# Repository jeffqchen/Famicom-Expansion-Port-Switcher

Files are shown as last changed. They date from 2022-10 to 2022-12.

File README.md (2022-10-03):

# Famicom Expansion Port Switcher Mod

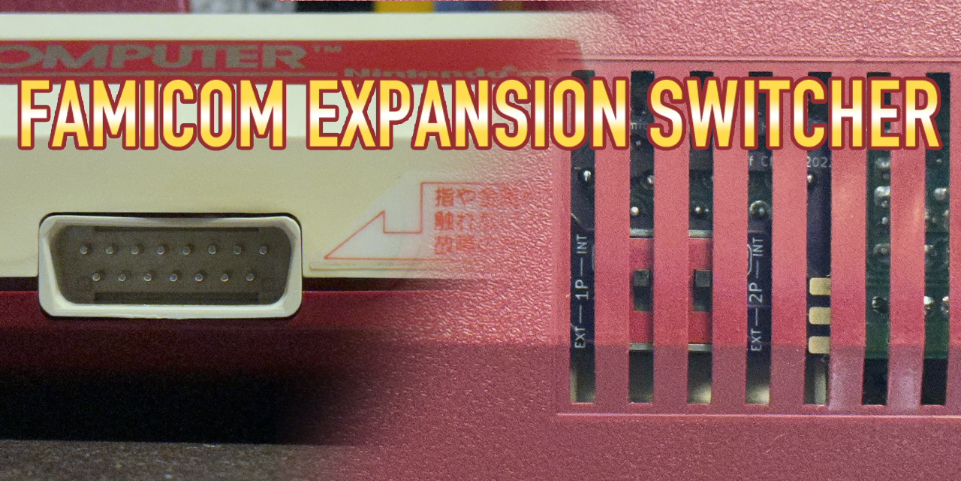
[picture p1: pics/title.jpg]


The expansion ports on the Japanese Famicom consoles have a problem - some western games are incompatible with the controllers connected to this port, due to the fact that this expansion port did not exist on the NES, and therefore was ignored by some devs.

Significant Titles Affected:
- Arkanoid II
- Battletoads
- Dragon's Lair
- Paperboy
- Pinball
- RoboCop 2/3
- Star Force
- Super Mario Bros. USA
- Snake Rattle'n'Roll
- Terminator 1/2
- Tetris (Tengen)
- Zelda II - The Adventure of Link

I created the [FamiCoun](https://github.com/jeffqchen/FamiCoun-Famicom-Front-Expansion-NES-SNES-Adapter) and the [TwinDiamond](https://github.com/jeffqchen/TwinDiamond-Twin-Famicom-Expansion-to-NES-SNES-Controller-Adapter) a few years ago and both suffered from this programming oversight by these devs. So it is only natural for me to take matters into my own hands to fix it.

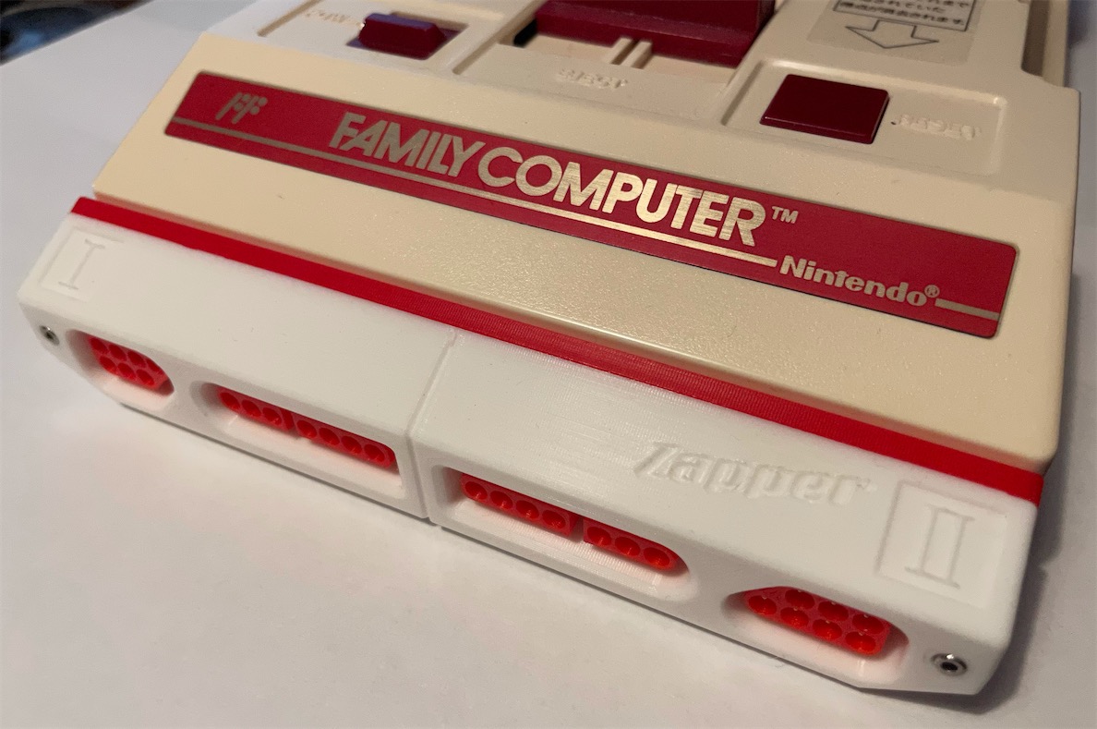
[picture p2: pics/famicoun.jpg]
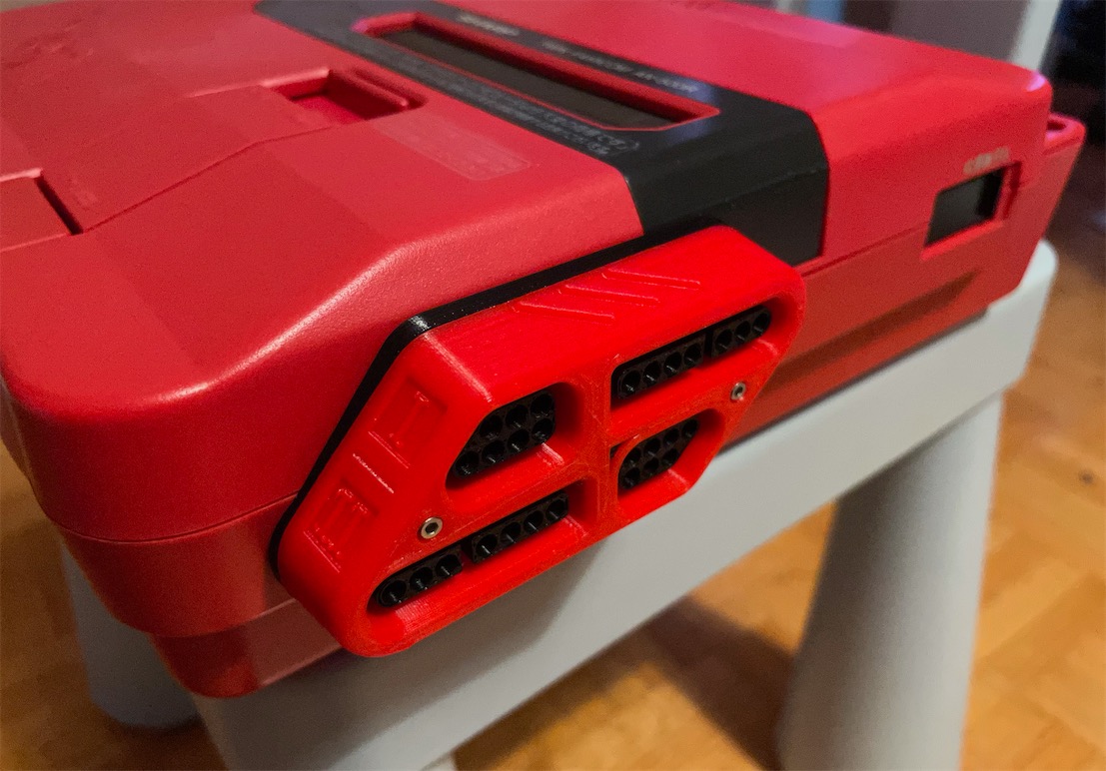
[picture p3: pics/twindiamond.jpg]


This switcher mod will enable you to switch the role of the expansion controllers between internal and external. It requires experience in console modding and might not be friendly for everybody. Please keep this in your mind before attempting.

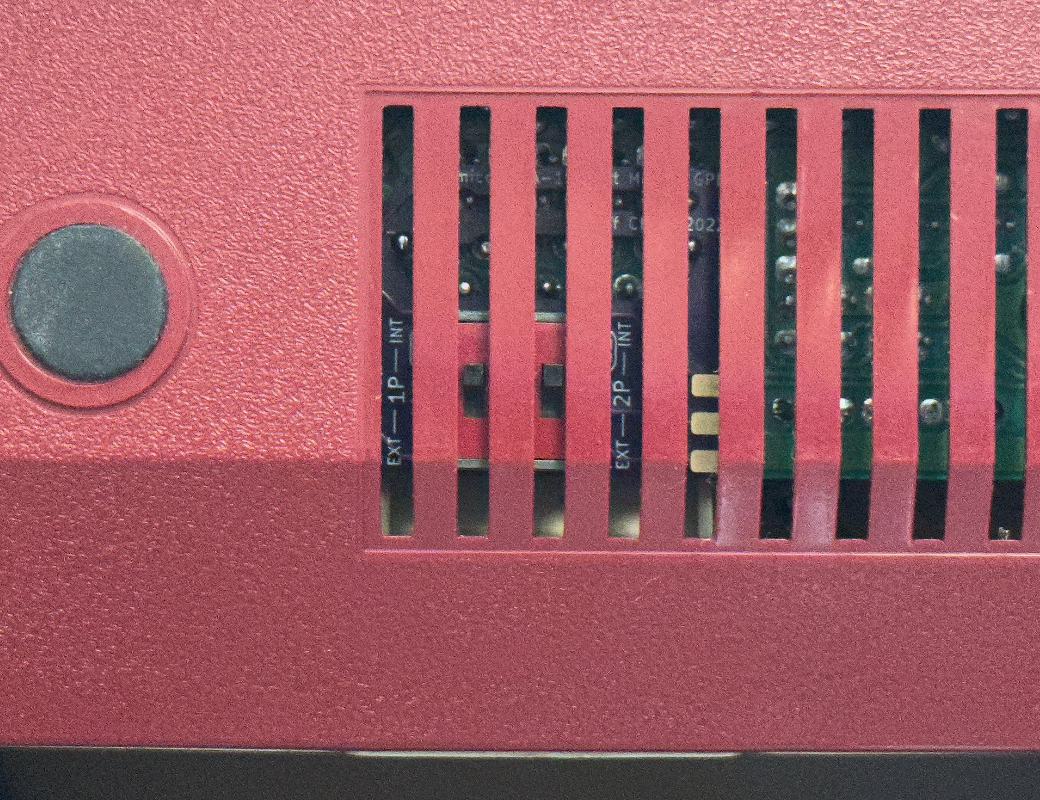
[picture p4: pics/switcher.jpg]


Details are provided in the [Project Wiki](https://github.com/jeffqchen/Famicom-Expansion-Port-Switcher/wiki), separated by console models and motherboard revisions.

-----
## Special Thanks
Voultar (for insisting on a proper logic circuit implementation)
- [Twitter](https://twitter.com/Voultar)

Redherring32 (for providing the board scan of Famicom GPM for reference)
- [Twitter](https://twitter.com/redherring32)
-----

Shield: [][cc-by-sa]

This work is licensed under a
[Creative Commons Attribution-ShareAlike 4.0 International License][cc-by-sa].

[][cc-by-sa]

[cc-by-sa]: http://creativecommons.org/licenses/by-sa/4.0/
[cc-by-sa-image]: https://licensebuttons.net/l/by-sa/4.0/88x31.png
[cc-by-sa-shield]: https://img.shields.io/badge/License-CC%20BY--SA%204.0-lightgrey.svg

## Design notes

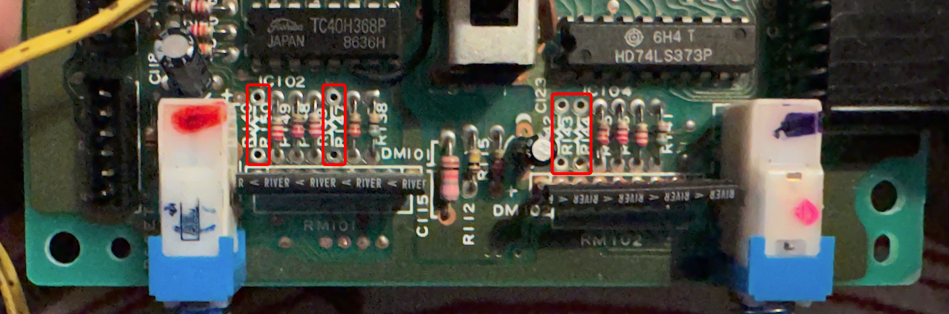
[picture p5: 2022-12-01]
pics/Twins/prepare_motherboard.jpg

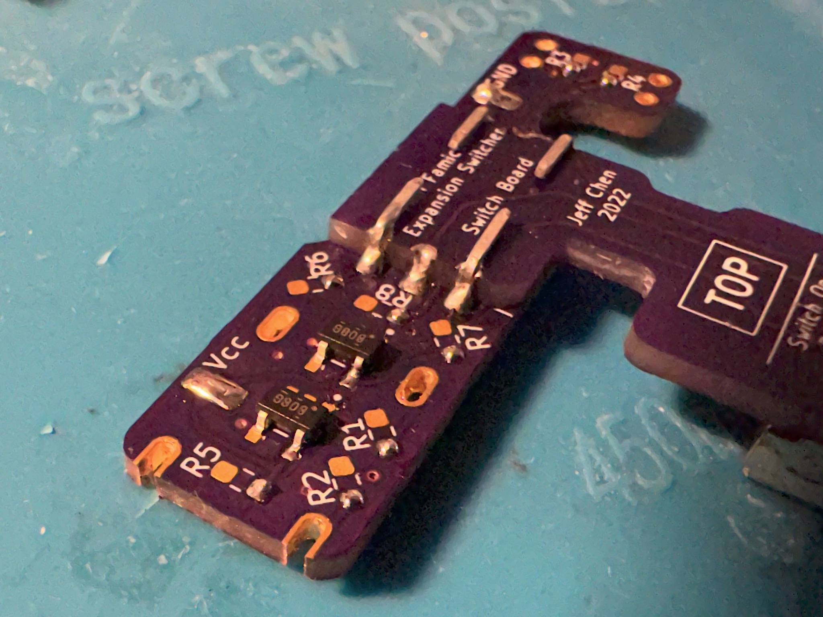
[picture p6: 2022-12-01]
pics/Twins/populate_01.jpg

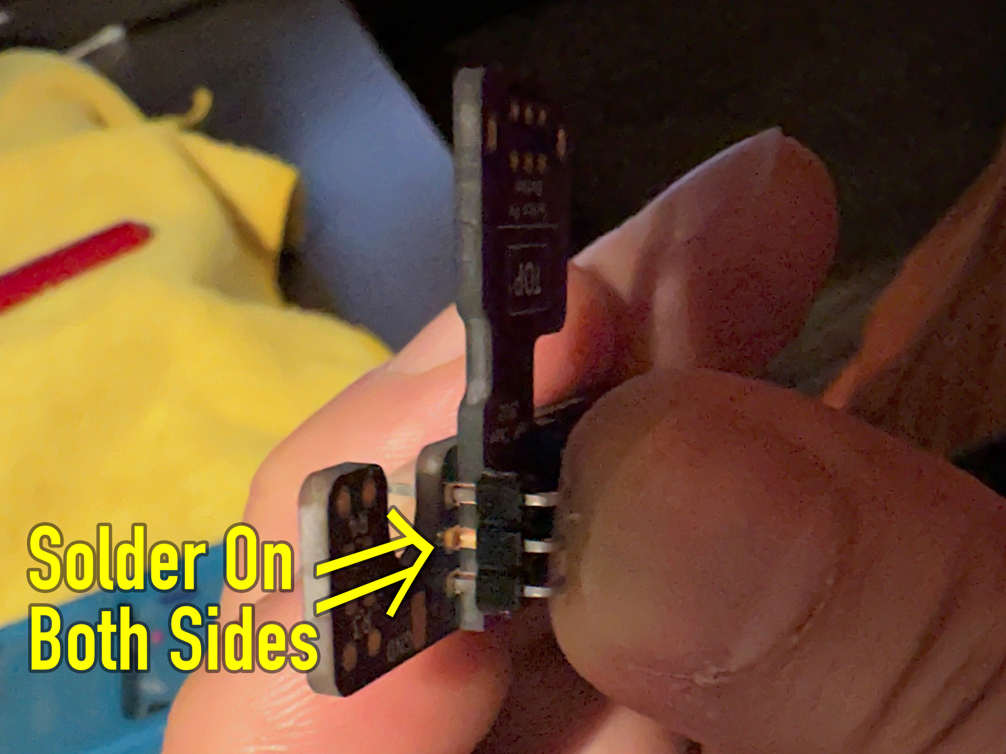
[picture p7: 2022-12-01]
pics/Twins/optional_pin_02.jpg

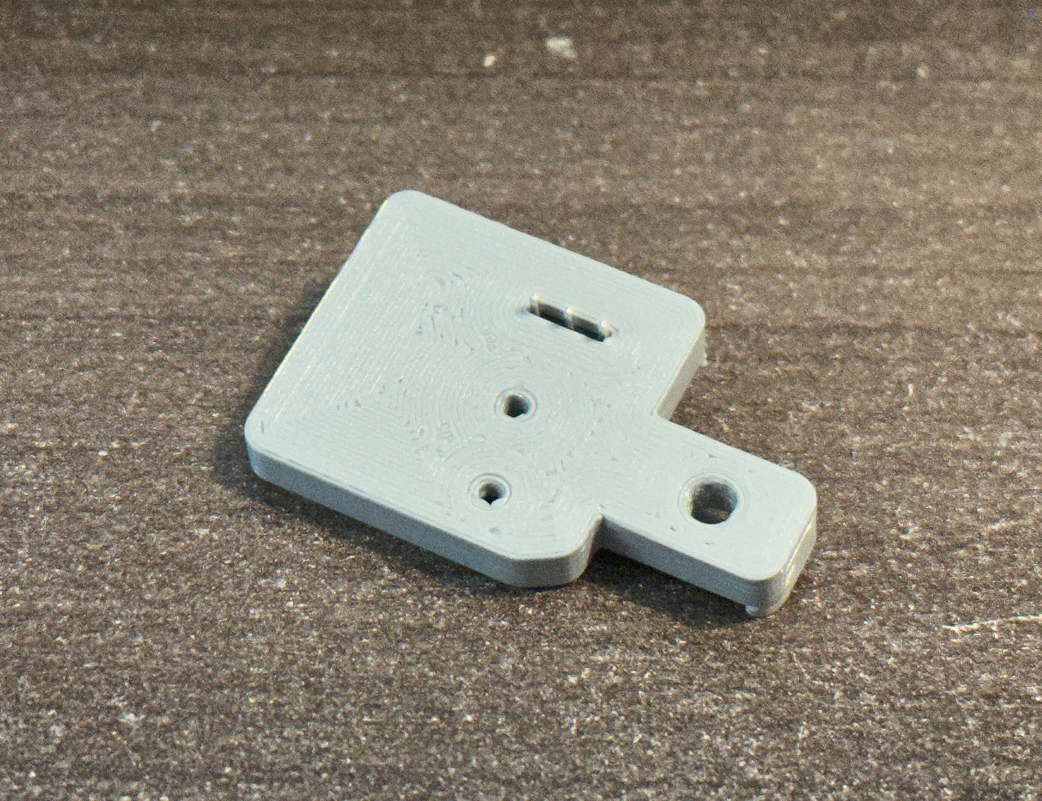
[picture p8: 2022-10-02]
pics/Famicom/GPM/trim_02.jpg

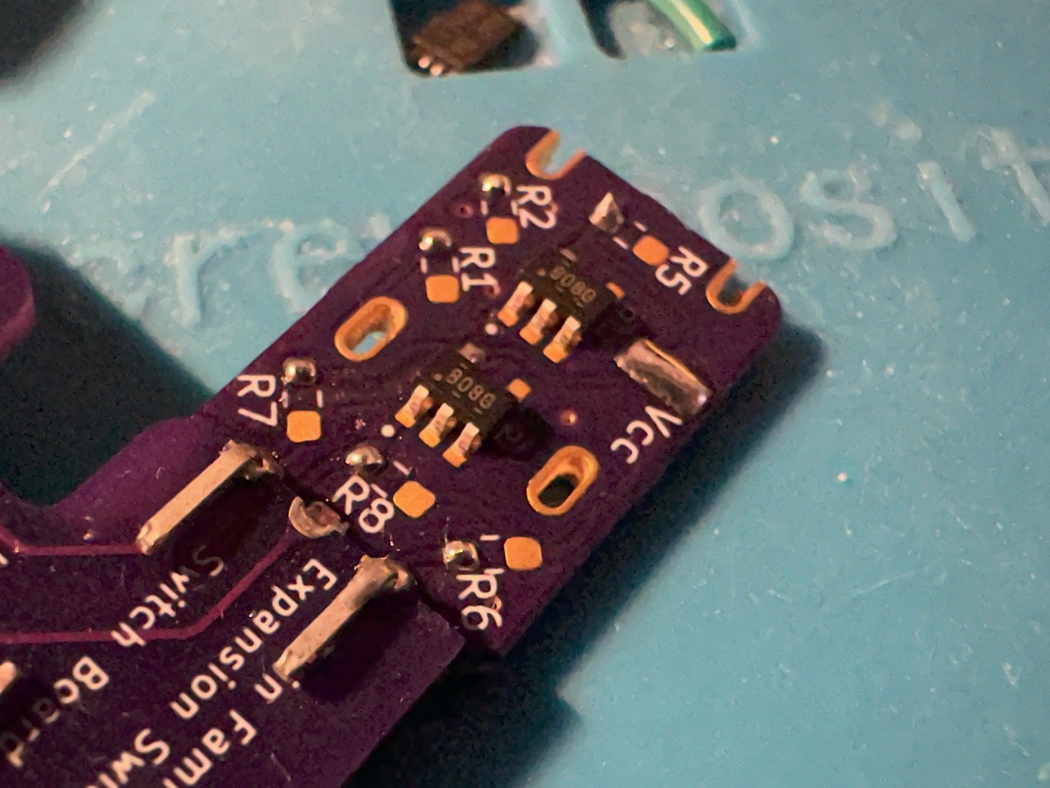
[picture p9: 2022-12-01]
pics/Twins/populate_02.jpg

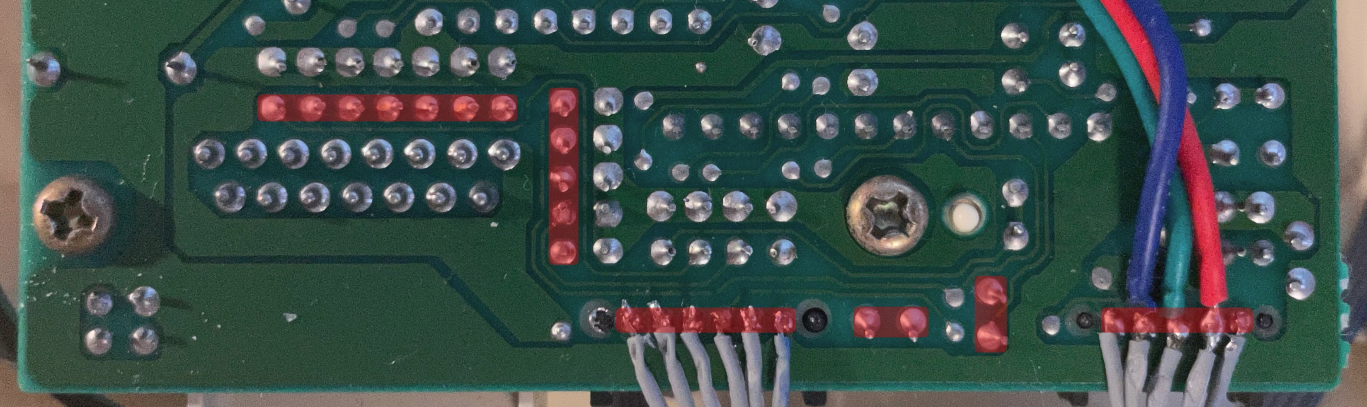
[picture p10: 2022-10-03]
pics/Famicom/GPM/straightenpins_01.jpg

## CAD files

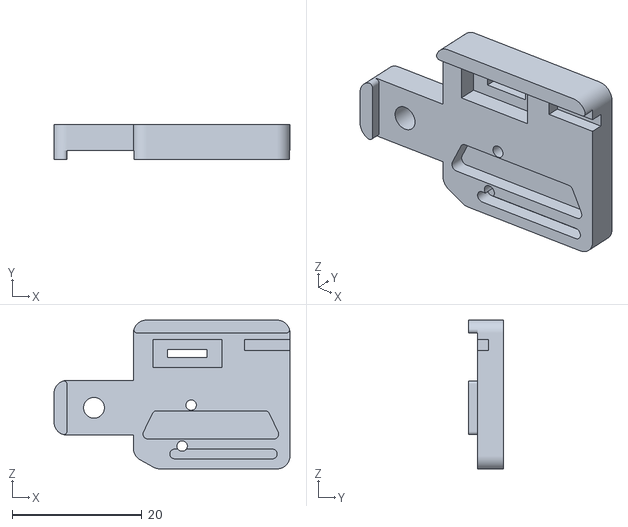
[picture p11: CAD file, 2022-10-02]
3D Print/Famicom/GPM/Drilling Jig.stl
36.3 x 5.40 x 22.9

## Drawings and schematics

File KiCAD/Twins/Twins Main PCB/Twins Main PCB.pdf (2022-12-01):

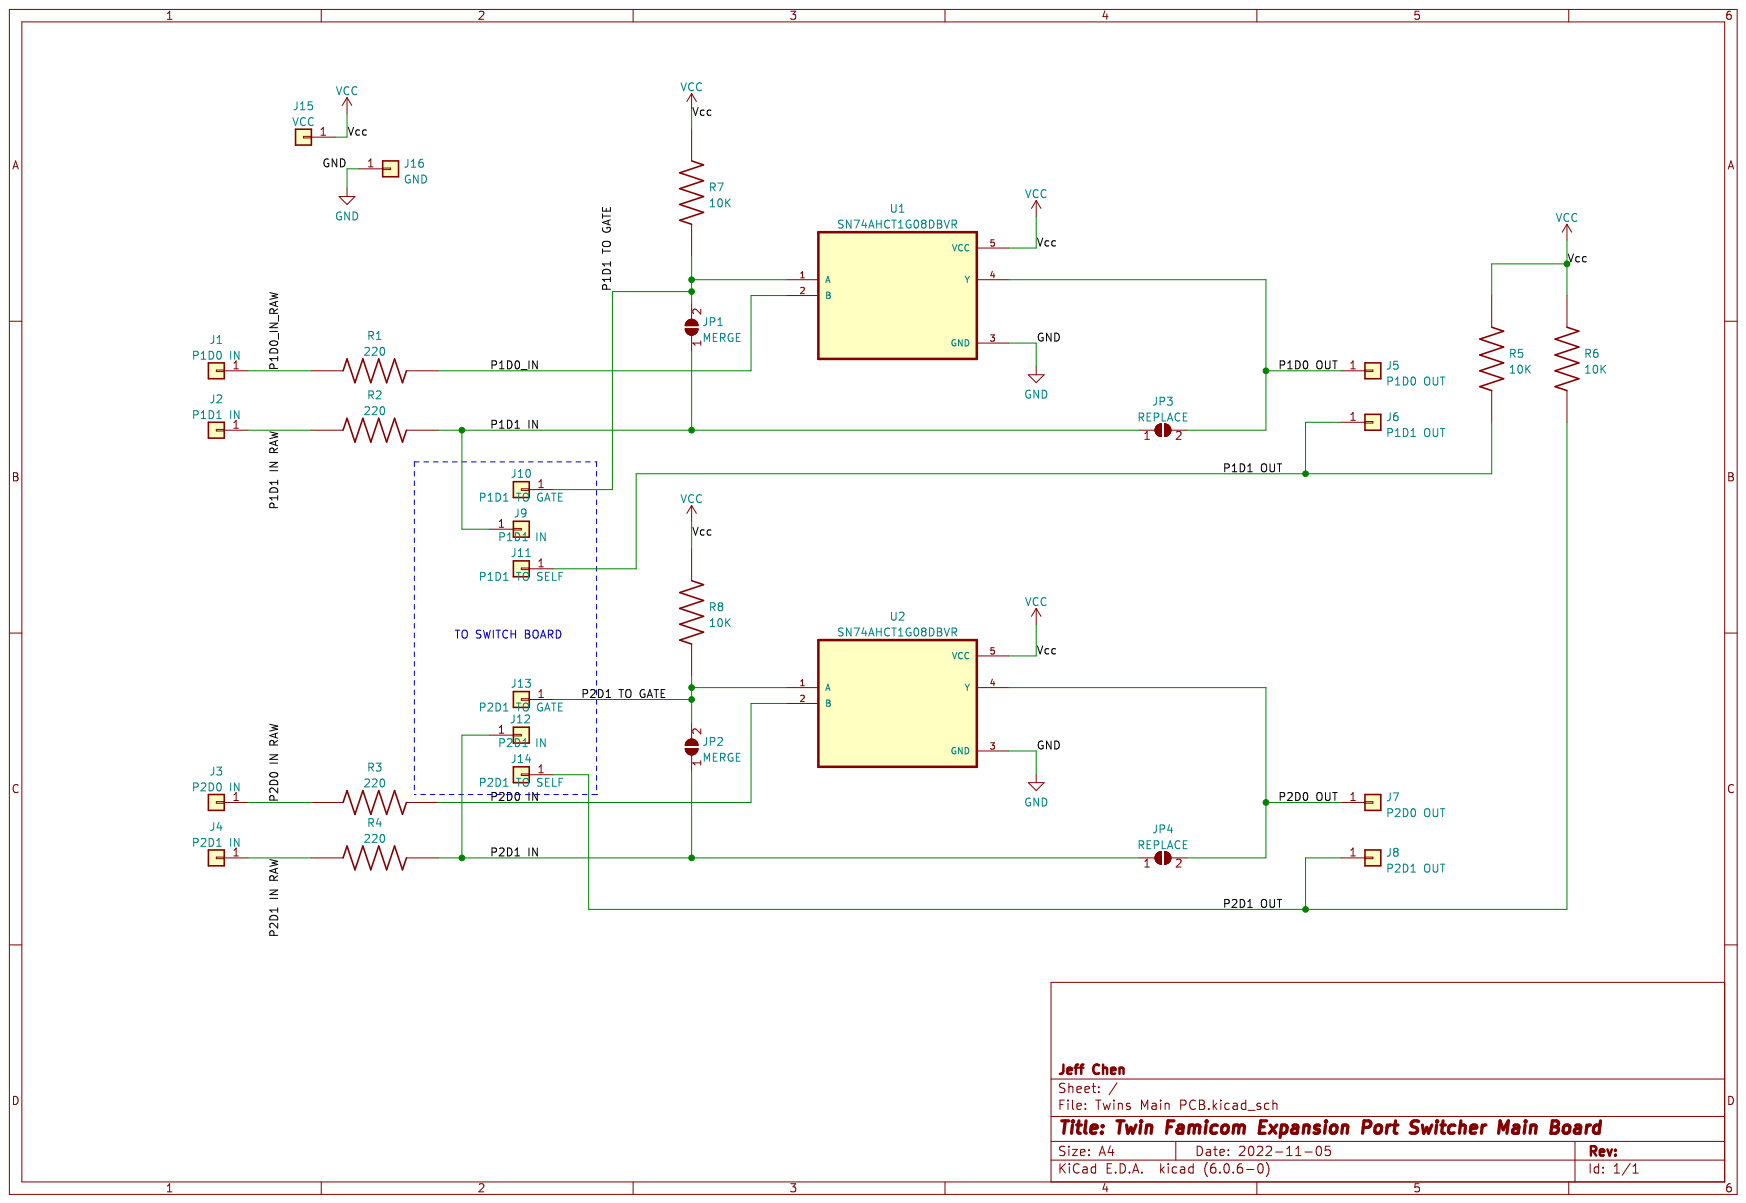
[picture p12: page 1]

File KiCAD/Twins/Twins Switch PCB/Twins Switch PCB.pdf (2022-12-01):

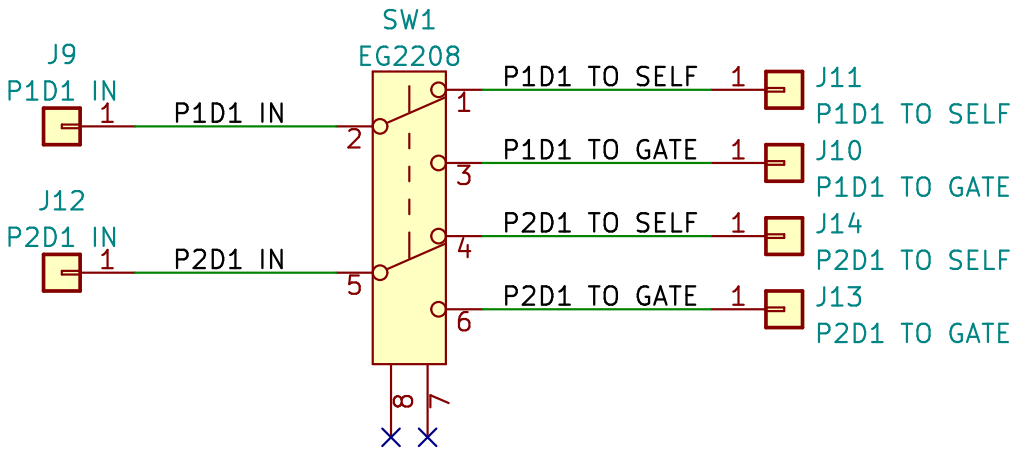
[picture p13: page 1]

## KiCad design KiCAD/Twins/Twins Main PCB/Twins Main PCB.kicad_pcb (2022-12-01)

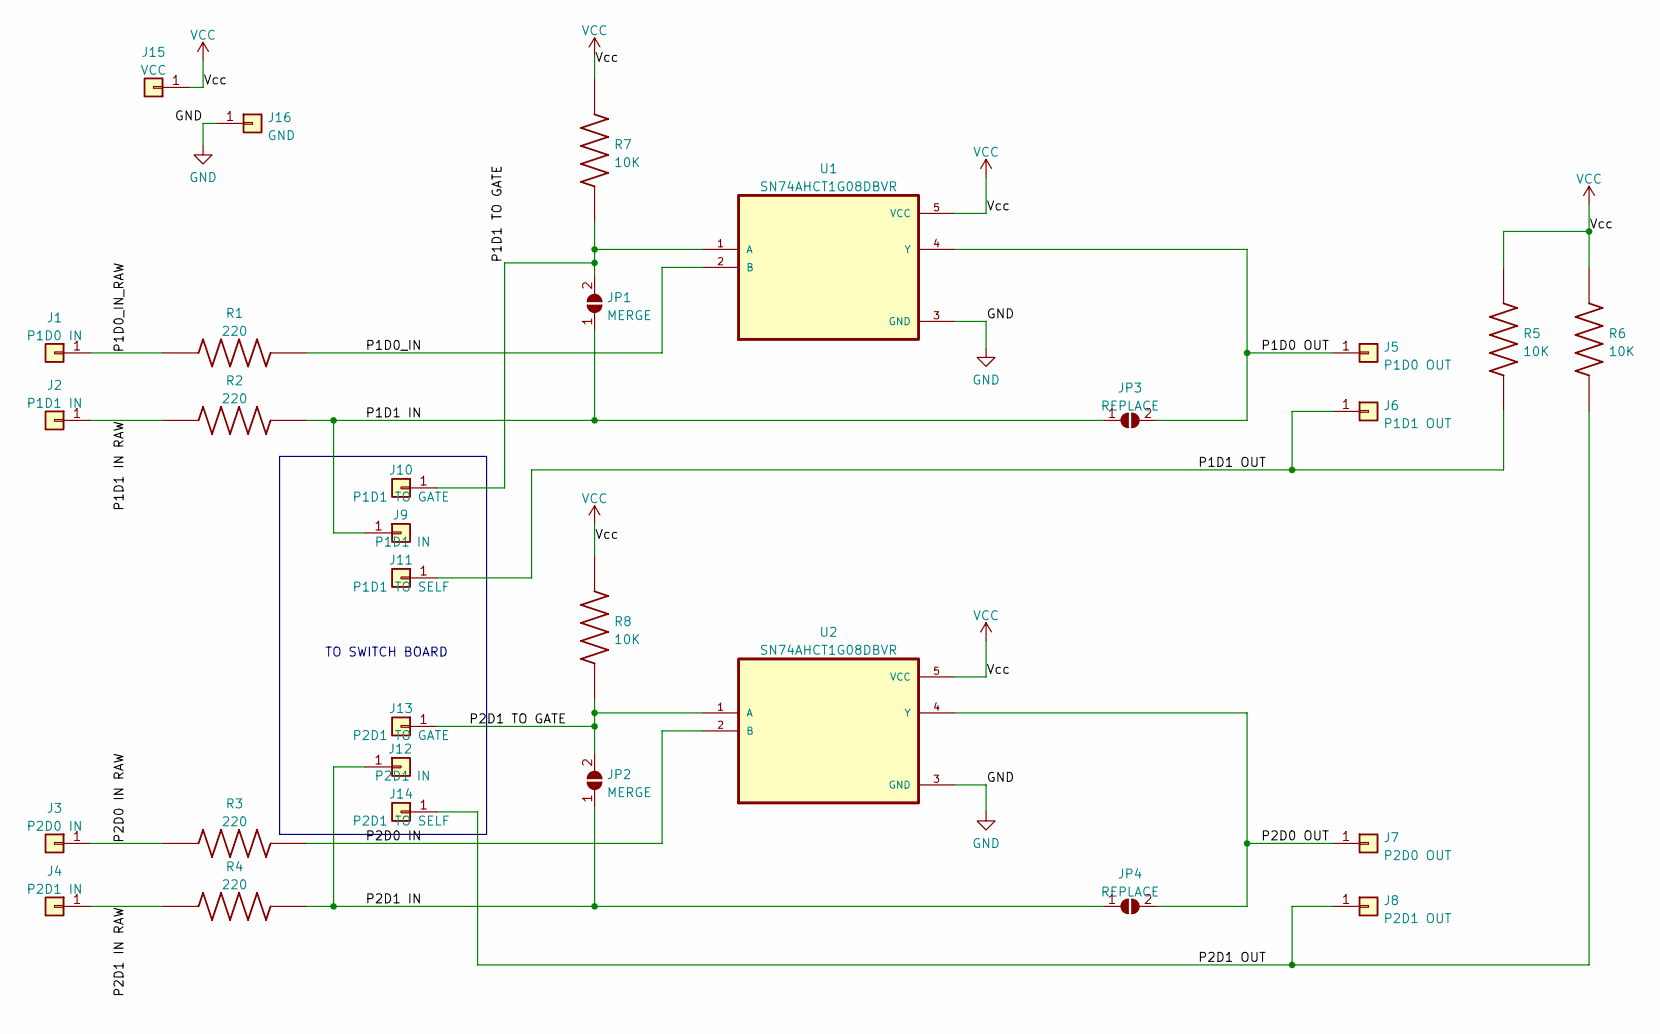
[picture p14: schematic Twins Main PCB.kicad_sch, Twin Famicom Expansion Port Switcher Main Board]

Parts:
J1: P1D0 IN; Long Via
J2: P1D1 IN; Long Via
J3: P2D0 IN; Short Via
J4: P2D1 IN; Short Via
J5: P1D0 OUT; Long Via
J6: P1D1 OUT; Long Via
J7: P2D0 OUT; Short Via
J8: P2D1 OUT; Short Via
J9: P1D1 IN; Landing Pad
J10: P1D1 TO GATE; Landing Pad
J11: P1D1 TO SELF; Landing Pad
J12: P2D1 IN; Landing Pad
J13: P2D1 TO GATE; Landing Pad
J14: P2D1 TO SELF; Landing Pad
J15: VCC; Single Pad Pin
J16: GND; Single Pad Pin
JP1, JP2: MERGE; SolderJumper-2_P1.3mm_Open_RoundedPad1.0x1.5mm
JP3, JP4: REPLACE; SolderJumper-2_P1.3mm_Open_RoundedPad1.0x1.5mm
R1, R2, R3, R4: 220; R_0603_1608Metric_Pad0.98x0.95mm_HandSolder
R5, R6, R7, R8: 10K; R_0603_1608Metric_Pad0.98x0.95mm_HandSolder
U1, U2: SN74AHCT1G08DBVR; SOT95P280X145-5N

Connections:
/P1D0 OUT: J5.1, JP3.2 (B), U1.4 (Y)
/P1D0_IN: R1.2, U1.2 (B)
/P1D0_IN_RAW: J1.1, R1.1
/P1D1 IN: J9.1, JP1.1 (A), JP3.1 (A), R2.2
/P1D1 IN RAW: J2.1, R2.1
/P1D1 OUT: J6.1, J11.1, R5.1
/P1D1 TO GATE: J10.1, JP1.2 (B), R7.1, U1.1 (A)
/P2D0 IN: R3.2, U2.2 (B)
/P2D0 IN RAW: J3.1, R3.1
/P2D0 OUT: J7.1, JP4.2 (B), U2.4 (Y)
/P2D1 IN: J12.1, JP2.1 (A), JP4.1 (A), R4.2
/P2D1 IN RAW: J4.1, R4.1
/P2D1 OUT: J8.1, J14.1, R6.1
/P2D1 TO GATE: J13.1, JP2.2 (B), R8.1, U2.1 (A)
GND: J16.1, U1.3 (GND), U2.3 (GND); also elsewhere on the board
VCC: J15.1, R5.2, R6.2, R7.2, R8.2, U1.5 (VCC), U2.5 (VCC); also elsewhere on the board

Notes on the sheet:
TO SWITCH BOARD

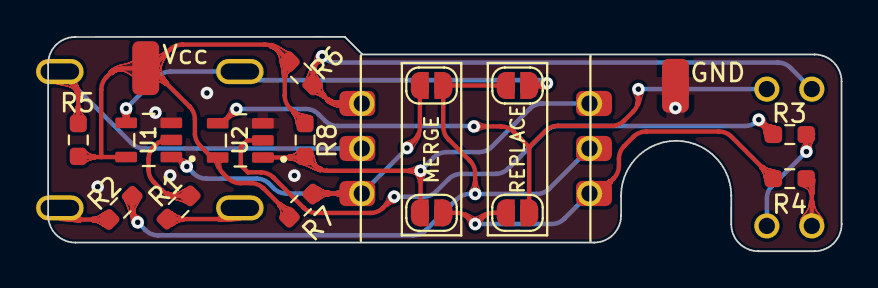
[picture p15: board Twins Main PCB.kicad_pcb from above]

Board: 2 copper layers, 44.1 x 11.9 mm, 30 parts (0 on the bottom side), 16 nets.

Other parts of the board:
GND: GND; Single Pad Pin
Vcc: VCC; Single Pad Pin

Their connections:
GND: GND.1; also elsewhere on the board
VCC: Vcc.1; also elsewhere on the board

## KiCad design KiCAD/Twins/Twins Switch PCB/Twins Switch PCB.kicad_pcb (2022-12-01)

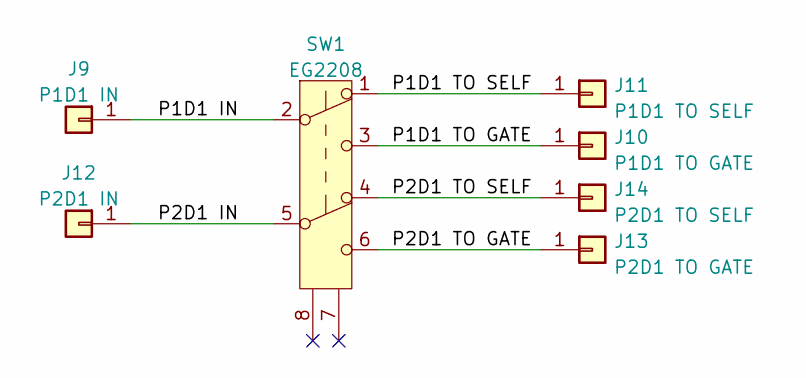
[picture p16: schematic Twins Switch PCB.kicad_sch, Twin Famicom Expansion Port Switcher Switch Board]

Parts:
J9: P1D1 IN; Short Via
J10: P1D1 TO GATE; Short Via
J11: P1D1 TO SELF; Short Via
J12: P2D1 IN; Short Via
J13: P2D1 TO GATE; Short Via
J14: P2D1 TO SELF; Short Via
SW1: EG2208; EG2208_DPDT_Switch

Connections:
/P1D1 IN: J9.1, SW1.2 (B)
/P1D1 TO GATE: J10.1, SW1.3 (C)
/P1D1 TO SELF: J11.1, SW1.1 (A)
/P2D1 IN: J12.1, SW1.5 (B)
/P2D1 TO GATE: J13.1, SW1.6 (C)
/P2D1 TO SELF: J14.1, SW1.4 (A)

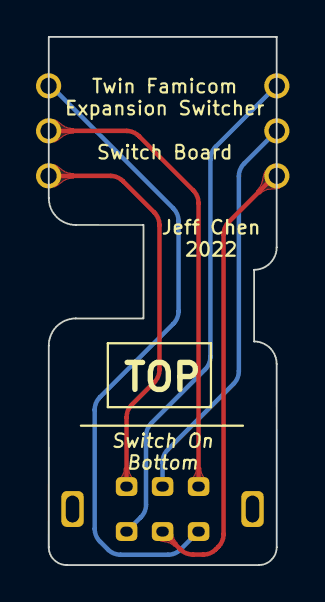
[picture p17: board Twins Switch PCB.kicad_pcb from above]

Board: 2 copper layers, 12.7 x 29.3 mm, 7 parts (1 on the bottom side), 6 nets.

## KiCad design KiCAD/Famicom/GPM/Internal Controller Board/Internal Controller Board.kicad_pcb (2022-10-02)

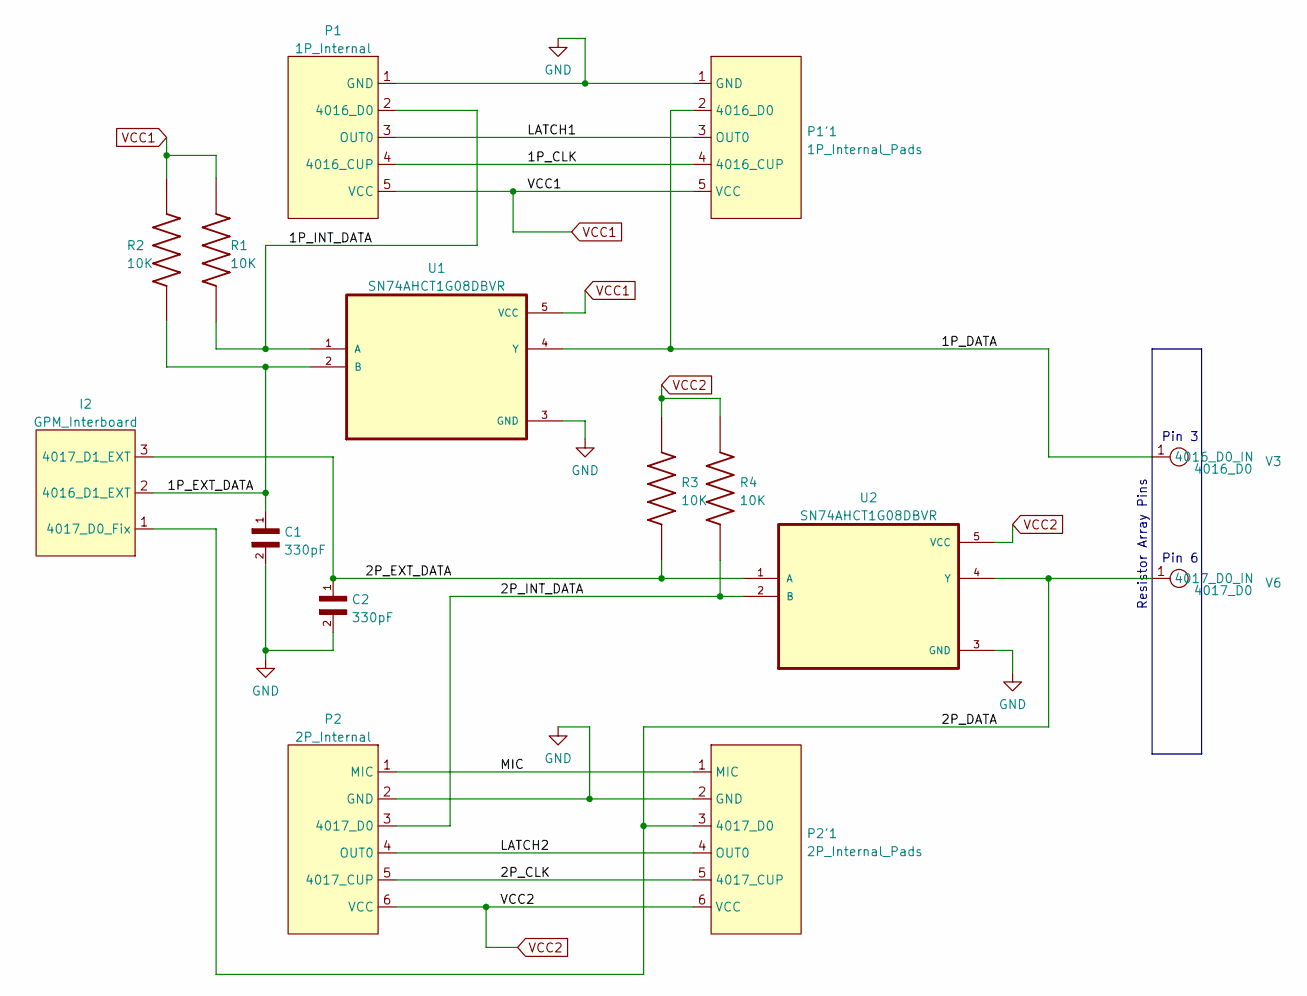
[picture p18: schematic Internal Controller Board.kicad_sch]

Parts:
C1, C2: 330pF; C_0603_1608Metric_Pad1.08x0.95mm_HandSolder
I2: GPM_Interboard; GPM Interboard
P1: 1P_Internal; 1P Internal
P1'1: 1P_Internal_Pads; 1P Internal Pads
P2: 2P_Internal; 2P Internal
P2'1: 2P_Internal_Pads; 2P Internal Pads
R1, R2, R3, R4: 10K; R_0603_1608Metric_Pad0.98x0.95mm_HandSolder
U1, U2: SN74AHCT1G08DBVR; SOT95P280X145-5N
V3: 4016_D0; Single Pad Pin
V6: 4017_D0; Single Pad Pin

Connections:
/1P_CLK: P1.4 (4016_CUP), P1'1.4 (4016_CUP)
/1P_DATA: P1'1.2 (4016_D0), U1.4 (Y), V3.1 (4016_D0_IN)
/1P_EXT_DATA: C1.1, I2.2 (4016_D1_EXT), R2.1, U1.2 (B)
/1P_INT_DATA: P1.2 (4016_D0), R1.1, U1.1 (A)
/2P_CLK: P2.5 (4017_CUP), P2'1.5 (4017_CUP)
/2P_DATA: I2.1 (4017_D0_Fix), P2'1.3 (4017_D0), U2.4 (Y), V6.1 (4017_D0_IN)
/2P_EXT_DATA: C2.1, I2.3 (4017_D1_EXT), R3.1, U2.1 (A)
/2P_INT_DATA: P2.3 (4017_D0), R4.1, U2.2 (B)
/LATCH1: P1.3 (OUT0), P1'1.3 (OUT0)
/LATCH2: P2.4 (OUT0), P2'1.4 (OUT0)
/MIC: P2.1 (MIC), P2'1.1 (MIC)
GND: C1.2, C2.2, P1.1 (GND), P1'1.1 (GND), P2.2 (GND), P2'1.2 (GND), U1.3 (GND), U2.3 (GND)
VCC1: P1.5 (VCC), P1'1.5 (VCC), R1.2, R2.2, U1.5 (VCC)
VCC2: P2.6 (VCC), P2'1.6 (VCC), R3.2, R4.2, U2.5 (VCC)

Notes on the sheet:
Pin 3
Pin 6
Resistor Array Pins

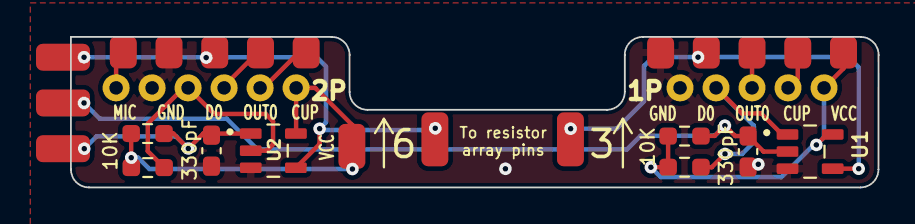
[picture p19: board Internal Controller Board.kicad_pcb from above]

Board: 2 copper layers, 44.9 x 8.4 mm, 15 parts (0 on the bottom side), 14 nets.

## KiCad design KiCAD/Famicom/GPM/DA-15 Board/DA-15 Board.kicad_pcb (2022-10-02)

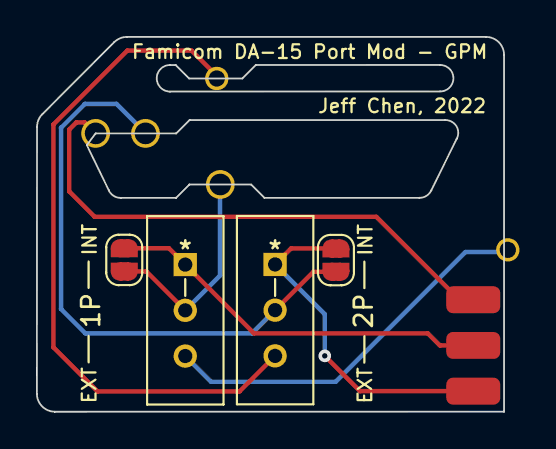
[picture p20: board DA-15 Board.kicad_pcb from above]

Board: 2 copper layers, 26.0 x 20.8 mm, 8 parts (0 on the bottom side), 7 nets.

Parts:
I1: GPM_Interboard; GPM Interboard
JP1, JP2: SolderJumper_2_Open; SolderJumper-2_P1.3mm_Open_RoundedPad1.0x1.5mm
P1: DA-15 Port; DA-15 Alternate
SW1, SW2: SS12SDP2_NKK; SS12SDP2
V1: 4016_D1; Single Via Pin
V2: 4017_D1; Single Via Pin

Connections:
/4016_D1: SW1.3, V1.1 (4016_D1_IN)
/4016_D1_EXT: JP1.2 (B), P1.13 (4016_D1), SW1.2
/4016_D1_INT: I1.2 (4016_D1_EXT), JP1.1 (A), SW1.1
/4017_D1: SW2.3, V2.1 (4017_D1_IN)
/4017_D1_EXT: JP2.2 (B), P1.7 (4017_D1), SW2.2
/4017_D1_INT: I1.3 (4017_D1_EXT), JP2.1 (A), SW2.1
/TO_EXT_4017_D0: I1.1 (4017_D0_Fix), P1.8 (4017_D0)

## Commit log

2022-12-01 Twins Mod Initial Upload
    [Twins Main PCB-B_Mask.gbr, Twins Main PCB-B_Paste.gbr, Twins Main PCB-B_Silkscreen.gbr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]
2022-12-01 Add indicators for resistors to remove

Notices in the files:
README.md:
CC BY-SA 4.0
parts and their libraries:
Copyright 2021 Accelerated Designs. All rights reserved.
